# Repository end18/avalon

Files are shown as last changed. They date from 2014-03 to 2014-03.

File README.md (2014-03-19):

Avalon Gen3 Hasher
------------------

This project contains a circuit board, firmware and cgminer/bfgminer patch to get the new Avalon Gen3 ASICs (A3233Q48) hashing.

**Board features:**

  - Very efficient (~90%) DC/DC converter to power the ASICs
  - Adjustable voltage (0.75 - 1.25 V) to choose between efficiency and overclocking
  - USB-Interface to connect to a host running cgminer or bfgminer
  - TWI interface to chain multiple boards together
  - 100% flat surface on the bottom side to mount a usual heatsink
  - On-board temperature management
  - Fan connector with rotation speed measurement and PWM-control
  - Indicator LED to report USB-activity
  - 4-layer PCB for optimal heat/current transportation

**cgminer/bfgminer patch features:**

  - Reporting temperature, real ASIC frequency and fan-speed back to the host
  - Control of ASIC frequency in a big range from 62.5 to 5000 MHz in smallest possible steps
  - Control of a desired temperature

**Get support:**

* [Forum thread]
* - Will be updated soon.

**Get a board:**

Someone is selling some boards in the [Forum thread] soon.

  [Forum thread]: comming soon.

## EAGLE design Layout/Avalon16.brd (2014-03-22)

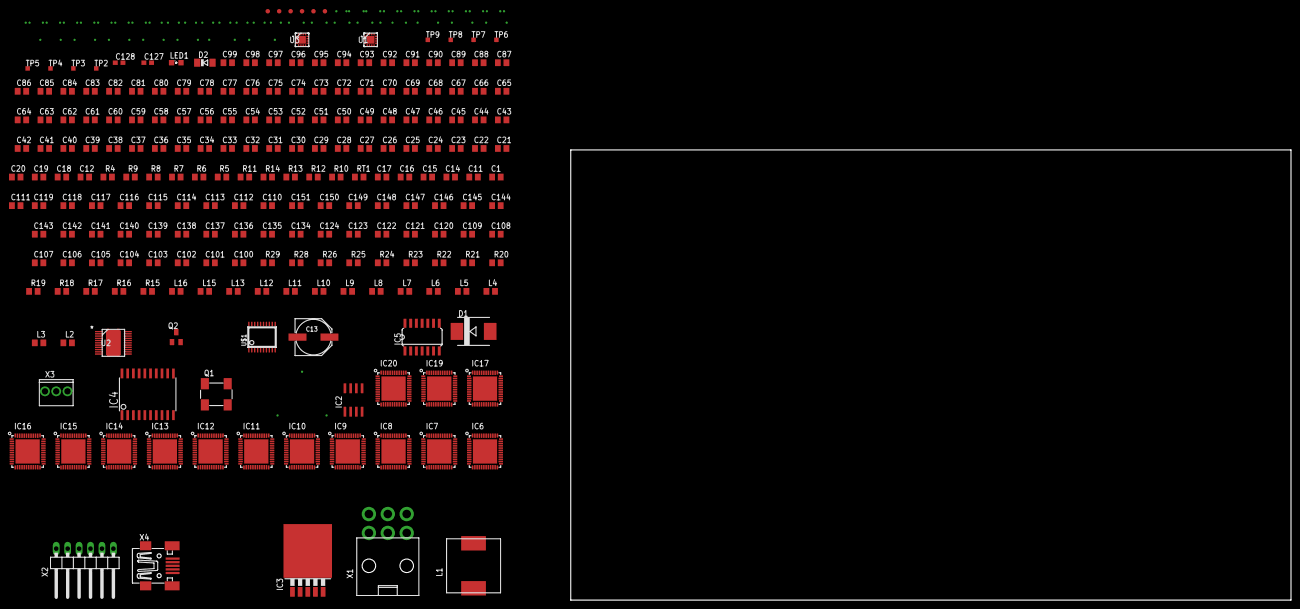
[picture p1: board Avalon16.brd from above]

Board: 2 copper layers, 160.0 x 100.0 mm, 264 parts (0 on the bottom side), 115 nets, no tracks yet.

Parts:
C1, C11, C14, C15, C16: 100n; C0805
C12, C18, C19, C20, C21, C22, C23, C24, C25, C26, C27, C28, C29, C30, C31, C32, C33, C34, C35, C36, C37, C38, C39, C40, C41, C42, C43, C44, C45, C46, C47, C48, C49, C50, C51, C52, C53, C54, C55, C56, C57, C58, C59, C60, C61, C62, C63, C64, C65, C66, C67, C68, C69, C70, C71, C72, C73, C74, C75, C76, C77, C78, C79, C80, C81, C82, C83, C84, C85, C86, C87, C88, C89, C90, C91, C92, C93, C94, C95, C96, C97, C98, C99, C100, C101, C102, C103, C104, C105, C106, C107, C108, C109, C110, C111, C112, C113, C114, C115, C116, C117, C118, C119, C120, C121, C122, C123, C124, C134, C135, C136, C137, C138, C139, C140, C141, C142, C143, C144, C145, C146, C147, C148, C149, C150, C151: 1µ; C0805
C13: 1000µ/6.3V/EEEFP0J102AP; PANASONIC_F
C17: 470p; C0805
C127, C128: 0.1µ; C0603
CAC_1: 1nF; 0603
CBST_1: 100nF; 0603
CINX_1, CINX_2: 100nF; 0603
CIN_1, CIN_6: 10uF; 0805
CIN_2, CIN_3, CIN_4, CIN_5: 22uF; 1812
COUT_1, COUT_6: 22uF; 0805
COUT_2, COUT_3, COUT_4, COUT_5: 100uF; 1812
CREG_1: 1uF; 1206
CR_1: 22nF; 0603
CSNUB_1: 2.2nF; 0603
CSS_1: 120pF; 0201
CSS_2: 220pF; 0201
CVDD_1: 4.7uF; 0805
D1: MBRS340T3G; SMC
D2: 4448; SOD80C
FID1, FID2, FID3, FID4, FID5, FID6: 1mm; FIDUCIAL
GND93: WB_GND
IC2: NB3L553DG; SO8
IC3: LM2576S-3.3; TO263-5
IC4: PIC16LF1459; SOIC20
IC5: 74HC02D; SO14
IC6, IC7, IC8, IC9, IC10, IC11, IC12, IC13, IC14, IC15, IC16, IC17, IC19, IC20: A3255Q48; QFN48
L1: 100µ / Würth 7447709101; WUERTH-7447709101
L2, L3, L4, L5, L6, L7, L8, L9, L10, L11, L12, L13, L15, L16: 100µ; L0805
L14, L18: 2.2uH; SRN8040
L17: 500nH; SER2009
LED1: green; SML0805
Q1: 7W-25-000MBB-T; 7W
Q2: IRFML8244TRPBF; SOT23
R4, R10, R11, R13: 10k; R0805
R5, R6: 390; R0805
R7, R8, R9, R12: 100; R0805
R14: 1k; R0805
R15, R16, R17, R18, R19, R20, R21, R22, R23, R24, R25, R26, R28, R29: 100k; R0805
RBST_1: 2.05; 0402
RENABLE_1: 1k; 0402
RENB_1: 100k; 0402
RENT_1: 200k; 0402
RFB1: 200k; 0402
RFB2: 24.9k; 0402
RFB3: 150k; 0402
RFB4: 187k; 0402
RFBB_1: 10k; 0402
RFBT_1: 2.49k; 0402
RPGOOD_1: 100k; 0402
RPG_1, RPG_2: 100k; 0402
RR_1: 66.5k; 0402
RSNUB_1: 3; 0402
RSS_1: 39k; 0603
RT1: 2k2; 0805
RTRIP_1: 180k; 0402
TP2, TP3, TP4, TP5, TP6, TP7, TP8, TP9: TPSQTP10SQ; TP10SQ
U1, U3: TPS62130RGTR; S-PVQFN-N16
U2: TPS53355DQPR; R-PSON-N22
U$1: GTL2003; TSSOP20
X1: Molex 45558-0003; MOLEX-45558-0003
X2: ISP; 1X06/270
X3: Molex 22-04-1031; MOLEX-22-04-1031
X4: Würth 65100516121 / TE 1734035-2; 32005-301

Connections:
1: CSS_1.2, U1.9
3: RFB1.2, RFB2.2, U1.5
4: L14.1, U1.1, U1.2, U1.3
6: RPG_1.2, U1.4
7: CAC_1.2, RFBB_1.1, RFBT_1.2, U2.1
10: CAC_1.1, CR_1.2, RR_1.1
11: CBST_1.2, RBST_1.1
13: CREG_1.1, RPGOOD_1.2, U2.18
14: CSNUB_1.1, RSNUB_1.2
15: RBST_1.2, U2.4
16: RENABLE_1.2, RENB_1.1, RENT_1.1
17: RENABLE_1.1, U2.2
18: RPGOOD_1.1, U2.3
19: RSS_1.1, U2.20
20: RTRIP_1.2, U2.21
24: CSS_2.2, U3.9
25: L18.1, U3.1, U3.2, U3.3
26: RFB3.2, RFB4.2, U3.5
27: RPG_2.2, U3.4
!MCLR: IC4.4, R7.1, X2.1
!RESET1: C26.2, IC6.44, R15.2
!RESET2: C27.2, IC7.44, R16.2
!RESET3: C36.2, IC8.44, R17.2
!RESET4: C45.2, IC9.44, R18.2
!RESET5: C54.2, IC10.44, R19.2
!RESET6: C63.2, IC11.44, R20.2
!RESET7: C72.2, IC12.44, R21.2
!RESET8: C81.2, IC13.44, R22.2
!RESET9: C90.2, IC14.44, R23.2
!RESET10: C99.2, IC15.44, R24.2
!RESET11: C12.2, IC16.44, R25.2
!RESET12: C116.2, IC17.44, R26.2
!RESET14: C134.2, IC19.44, R28.2
!RESET15: C143.2, IC20.44, R29.2
+0V9: COUT_1.1, IC8.7, IC9.7, IC10.7, IC12.7, IC13.7, IC14.7, IC15.7, IC16.7, IC17.7, IC19.7, IC20.7, L14.2, RFB2.1, RPG_1.1, U1.7, U1.14
+1V8: C127.2, COUT_6.1, IC6.24, IC6.37, IC7.24, IC7.37, IC8.24, IC8.37, IC9.24, IC9.37, IC10.24, IC10.37, IC11.24, IC11.37, IC12.24, IC12.37, IC13.24, IC13.37, IC14.24, IC14.37, IC15.24, IC15.37, IC16.24, IC16.37, IC17.24, IC17.37, IC19.24, IC19.37, IC20.24, IC20.37, L2.1, L3.1, L4.1, L5.1, L6.1, L7.1, L8.1, L9.1, L10.1, L11.1, L12.1, L13.1, L15.1, L16.1, L18.2, R15.1, R16.1, R17.1, R18.1, R19.1, R20.1, R21.1, R22.1, R23.1, R24.1, R25.1, R26.1, R28.1, R29.1, RFB4.1, RPG_2.1, U3.7, U3.14, U$1.2
+3V3: C1.2, C11.2, C13.+, C14.2, C15.2, C23.2, C24.2, C34.2, C35.2, C43.2, C44.2, C52.2, C53.2, C61.2, C62.2, C70.2, C71.2, C79.2, C80.2, C88.2, C89.2, C97.2, C98.2, C106.2, C107.2, C114.2, C115.2, C123.2, C124.2, C128.2, C141.2, C142.2, C150.2, C151.2, IC2.1, IC2.8, IC3.4, IC4.1, IC5.14, L1.2, Q1.4, R4.1, R5.1, R6.1, R10.1, R11.1, RT1.2, TP6.TP, U$1.19, U$1.20, X2.2
+12V: CINX_1.1, CINX_2.1, CIN_1.1, CIN_2.1, CIN_3.1, CIN_4.1, CIN_5.1, CIN_6.1, CVDD_1.1, D2.C, IC3.1, RENT_1.2, U1.10, U1.11, U1.12, U1.13, U2.12, U2.13, U2.14, U2.15, U2.16, U2.17, U2.19, U3.10, U3.11, U3.12, U3.13, X1.1, X1.2, X1.3, X3.2
CLK1: IC2.2, IC6.9, IC7.9, IC8.9, IC9.9, IC10.9, IC19.9, IC20.9
CLK2: IC2.3, IC11.9, IC12.9, IC13.9, IC14.9, IC15.9, IC16.9, IC17.9
CONFIG1_1V8_N: IC6.2, U$1.4
CONFIG1_1V8_P: IC6.1, U$1.3
CONFIG1_1_2_N: IC6.35, IC7.2
CONFIG1_1_2_P: IC6.36, IC7.1
CONFIG1_2_3_N: IC7.35, IC8.2
CONFIG1_2_3_P: IC7.36, IC8.1
CONFIG1_3_4_N: IC8.35, IC9.2
CONFIG1_3_4_P: IC8.36, IC9.1
CONFIG1_4_5_N: IC9.35, IC10.2
CONFIG1_4_5_P: IC9.36, IC10.1
CONFIG1_5_6_N: IC10.35, IC19.2
CONFIG1_5_6_P: IC10.36, IC19.1
CONFIG1_6_7_N: IC19.35, IC20.2
CONFIG1_6_7_P: IC19.36, IC20.1
CONFIG1_N: IC4.8, U$1.17
CONFIG1_P: IC4.9, U$1.18
CONFIG2_1V8_N: IC11.2, U$1.6
CONFIG2_1V8_P: IC11.1, U$1.5
CONFIG2_1_2_N: IC11.35, IC12.2
CONFIG2_1_2_P: IC11.36, IC12.1
CONFIG2_2_3_N: IC12.35, IC13.2
CONFIG2_2_3_P: IC12.36, IC13.1
CONFIG2_3_4_N: IC13.35, IC14.2
CONFIG2_3_4_P: IC13.36, IC14.1
CONFIG2_4_5_N: IC14.35, IC15.2
CONFIG2_4_5_P: IC14.36, IC15.1
CONFIG2_5_6_N: IC15.35, IC16.2
CONFIG2_5_6_P: IC15.36, IC16.1
CONFIG2_6_7_N: IC16.35, IC17.2
CONFIG2_6_7_P: IC16.36, IC17.1
CONFIG2_N: IC4.7, U$1.15
CONFIG2_P: IC4.6, U$1.16
DVDD: C18.2, C19.2, C20.2, C21.2, C22.2, C29.2, C30.2, C31.2, C32.2, C33.2, C38.2, C39.2, C40.2, C41.2, C42.2, C47.2, C48.2, C49.2, C50.2, C51.2, C56.2, C57.2, C58.2, C59.2, C60.2, C65.2, C66.2, C67.2, C68.2, C69.2, C74.2, C75.2, C76.2, C77.2, C78.2, C83.2, C84.2, C85.2, C86.2, C87.2, C92.2, C93.2, C94.2, C95.2, C96.2, C101.2, C102.2, C103.2, C104.2, C105.2, C109.2, C110.2, C111.2, C112.2, C113.2, C118.2, C119.2, C120.2, C121.2, C122.2, C136.2, C137.2, C138.2, C139.2, C140.2, C145.2, C146.2, C147.2, C148.2, C149.2, CBST_1.1, COUT_2.1, COUT_3.1, COUT_4.1, COUT_5.1, CR_1.1, CSNUB_1.2, IC6.3, IC6.4, IC6.10, IC6.11, IC6.13, IC6.14, IC6.15, IC6.18, IC6.19, IC6.20, IC6.21, IC6.22, IC6.25, IC6.26, IC6.28, IC6.29, IC6.30, IC6.31, IC6.32, IC6.33, IC6.34, IC6.39, IC6.40, IC6.41, IC6.42, IC6.45, IC6.46, IC6.47, IC6.48, IC7.3, IC7.4, IC7.10, IC7.11, IC7.13, IC7.14, IC7.15, IC7.18, IC7.19, IC7.20, IC7.21, IC7.22, IC7.25, IC7.26, IC7.28, IC7.29, IC7.30, IC7.31, IC7.32, IC7.33, IC7.34, IC7.39, IC7.40, IC7.41, IC7.42, IC7.45, IC7.46, IC7.47, IC7.48, IC8.3, IC8.4, IC8.10, IC8.11, IC8.13, IC8.14, IC8.15, IC8.18, IC8.19, IC8.20, IC8.21, IC8.22, IC8.25, IC8.26, IC8.28, IC8.29, IC8.30, IC8.31, IC8.32, IC8.33, IC8.34, IC8.39, IC8.40, IC8.41, IC8.42, IC8.45, IC8.46, IC8.47, IC8.48, IC9.3, IC9.4, IC9.10, IC9.11, IC9.13, IC9.14, IC9.15, IC9.18, IC9.19, IC9.20, IC9.21, IC9.22, IC9.25, IC9.26, IC9.28, IC9.29, IC9.30, IC9.31, IC9.32, IC9.33, IC9.34, IC9.39, IC9.40, IC9.41, IC9.42, IC9.45, IC9.46, IC9.47, IC9.48, IC10.3, IC10.4, IC10.10, IC10.11, IC10.13, IC10.14, IC10.15, IC10.18, IC10.19, IC10.20, IC10.21, IC10.22, IC10.25, IC10.26, IC10.28, IC10.29, IC10.30, IC10.31, IC10.32, IC10.33, IC10.34, IC10.39, IC10.40, IC10.41, IC10.42, IC10.45, IC10.46, IC10.47, IC10.48, IC11.3, IC11.4, IC11.10, IC11.11, IC11.13, IC11.14, IC11.15, IC11.18, IC11.19, IC11.20, IC11.21, IC11.22, IC11.25, IC11.26, IC11.28, IC11.29, IC11.30, IC11.31, IC11.32, IC11.33, IC11.34, IC11.39, IC11.40, IC11.41, IC11.42, IC11.45, IC11.46, IC11.47, IC11.48, IC12.3, IC12.4, IC12.10, IC12.11, IC12.13, IC12.14, IC12.15, IC12.18, IC12.19, IC12.20, IC12.21, IC12.22, IC12.25, IC12.26, IC12.28, IC12.29, IC12.30, IC12.31, IC12.32, IC12.33, IC12.34, IC12.39, IC12.40, IC12.41, IC12.42, IC12.45, IC12.46, IC12.47, IC12.48, IC13.3, IC13.4, IC13.10, IC13.11, IC13.13, IC13.14, IC13.15, IC13.18, IC13.19, IC13.20, IC13.21, IC13.22, IC13.25, IC13.26, IC13.28, IC13.29, IC13.30, IC13.31, IC13.32, IC13.33, IC13.34, IC13.39, IC13.40, IC13.41, IC13.42, IC13.45, IC13.46, IC13.47, IC13.48, IC14.3, IC14.4, IC14.10, IC14.11, IC14.13, IC14.14, IC14.15, IC14.18, IC14.19, IC14.20, IC14.21, IC14.22, IC14.25, IC14.26, IC14.28, IC14.29, IC14.30, IC14.31, IC14.32, IC14.33, IC14.34, IC14.39, IC14.40, IC14.41, IC14.42, IC14.45, IC14.46, IC14.47, IC14.48, IC15.3, IC15.4, IC15.10, IC15.11, IC15.13, IC15.14, IC15.15, IC15.18, IC15.19, IC15.20, IC15.21, IC15.22, IC15.25, IC15.26, IC15.28, IC15.29, IC15.30, IC15.31, IC15.32, IC15.33, IC15.34, IC15.39, IC15.40, IC15.41, IC15.42, IC15.45, IC15.46, IC15.47, IC15.48, IC16.3, IC16.4, IC16.10, IC16.11, IC16.13, IC16.14, IC16.15, IC16.18, IC16.19, IC16.20, IC16.21, IC16.22, IC16.25, IC16.26, IC16.28, IC16.29, IC16.30, IC16.31, IC16.32, IC16.33, IC16.34, IC16.39, IC16.40, IC16.41, IC16.42, IC16.45, IC16.46, IC16.47, IC16.48, IC17.3, IC17.4, IC17.10, IC17.11, IC17.13, IC17.14, IC17.15, IC17.18, IC17.19, IC17.20, IC17.21, IC17.22, IC17.25, IC17.26, IC17.28, IC17.29, IC17.30, IC17.31, IC17.32, IC17.33, IC17.34, IC17.39, IC17.40, IC17.41, IC17.42, IC17.45, IC17.46, IC17.47, IC17.48, IC19.3, IC19.4, IC19.10, IC19.11, IC19.13, IC19.14, IC19.15, IC19.18, IC19.19, IC19.20, IC19.21, IC19.22, IC19.25, IC19.26, IC19.28, IC19.29, IC19.30, IC19.31, IC19.32, IC19.33, IC19.34, IC19.39, IC19.40, IC19.41, IC19.42, IC19.45, IC19.46, IC19.47, IC19.48, IC20.3, IC20.4, IC20.10, IC20.11, IC20.13, IC20.14, IC20.15, IC20.18, IC20.19, IC20.20, IC20.21, IC20.22, IC20.25, IC20.26, IC20.28, IC20.29, IC20.30, IC20.31, IC20.32, IC20.33, IC20.34, IC20.39, IC20.40, IC20.41, IC20.42, IC20.45, IC20.46, IC20.47, IC20.48, L17.1, L17.2, RFBT_1.1, RR_1.2, U2.6, U2.7, U2.8, U2.9, U2.10, U2.11
FAN_PWM: IC4.5, R12.1
GND: C1.1, C11.1, C12.1, C13.-, C14.1, C15.1, C16.1, C17.1, C18.1, C19.1, C20.1, C21.1, C22.1, C23.1, C24.1, C25.2, C26.1, C27.1, C28.2, C29.1, C30.1, C31.1, C32.1, C33.1, C34.1, C35.1, C36.1, C37.2, C38.1, C39.1, C40.1, C41.1, C42.1, C43.1, C44.1, C45.1, C46.2, C47.1, C48.1, C49.1, C50.1, C51.1, C52.1, C53.1, C54.1, C55.2, C56.1, C57.1, C58.1, C59.1, C60.1, C61.1, C62.1, C63.1, C64.2, C65.1, C66.1, C67.1, C68.1, C69.1, C70.1, C71.1, C72.1, C73.2, C74.1, C75.1, C76.1, C77.1, C78.1, C79.1, C80.1, C81.1, C82.2, C83.1, C84.1, C85.1, C86.1, C87.1, C88.1, C89.1, C90.1, C91.2, C92.1, C93.1, C94.1, C95.1, C96.1, C97.1, C98.1, C99.1, C100.2, C101.1, C102.1, C103.1, C104.1, C105.1, C106.1, C107.1, C108.2, C109.1, C110.1, C111.1, C112.1, C113.1, C114.1, C115.1, C116.1, C117.2, C118.1, C119.1, C120.1, C121.1, C122.1, C123.1, C124.1, C127.1, C128.1, C134.1, C135.2, C136.1, C137.1, C138.1, C139.1, C140.1, C141.1, C142.1, C143.1, C144.2, C145.1, C146.1, C147.1, C148.1, C149.1, C150.1, C151.1, CINX_1.2, CINX_2.2, CIN_1.2, CIN_2.2, CIN_3.2, CIN_4.2, CIN_5.2, CIN_6.2, COUT_1.2, COUT_2.2, COUT_3.2, COUT_4.2, COUT_5.2, COUT_6.2, CREG_1.2, CSS_1.1, CSS_2.1, CVDD_1.2, D1.A, GND93.1, IC2.4, IC3.3, IC3.5, IC3.6, IC4.20, IC5.7, IC6.5, IC6.8, IC6.12, IC6.23, IC6.27, IC6.38, IC6.EXP, IC7.5, IC7.8, IC7.12, IC7.23, IC7.27, IC7.38, IC7.EXP, IC8.5, IC8.8, IC8.12, IC8.23, IC8.27, IC8.38, IC8.EXP, IC9.5, IC9.8, IC9.12, IC9.23, IC9.27, IC9.38, IC9.EXP, IC10.5, IC10.8, IC10.12, IC10.23, IC10.27, IC10.38, IC10.EXP, IC11.5, IC11.8, IC11.12, IC11.23, IC11.27, IC11.38, IC11.EXP, IC12.5, IC12.8, IC12.12, IC12.23, IC12.27, IC12.38, IC12.EXP, IC13.5, IC13.8, IC13.12, IC13.23, IC13.27, IC13.38, IC13.EXP, IC14.5, IC14.8, IC14.12, IC14.23, IC14.27, IC14.38, IC14.EXP, IC15.5, IC15.8, IC15.12, IC15.23, IC15.27, IC15.38, IC15.EXP, IC16.5, IC16.8, IC16.12, IC16.23, IC16.27, IC16.38, IC16.EXP, IC17.5, IC17.8, IC17.12, IC17.23, IC17.27, IC17.38, IC17.EXP, IC19.5, IC19.8, IC19.12, IC19.23, IC19.27, IC19.38, IC19.EXP, IC20.5, IC20.8, IC20.12, IC20.23, IC20.27, IC20.38, IC20.EXP, LED1.C, Q1.2, Q2.2, R13.2, R14.2, RENB_1.2, RFB1.1, RFB3.1, RFBB_1.2, RSNUB_1.1, RSS_1.2, RTRIP_1.1, TP9.TP, U1.6, U1.8, U1.15, U1.16, U1.17, U2.23, U3.6, U3.8, U3.15, U3.16, U3.17, U$1.1, X1.4, X1.5, X1.6, X2.3, X4.5, X4.M1, X4.M2, X4.M3, X4.M4
ICSPCLK: IC4.15, X2.5
ICSPDAT: IC4.16, X2.4
LED: IC4.2, R9.2
unnamed: IC20.36, TP2.TP
unnamed: C16.2, IC4.17
unnamed: D1.C, IC3.2, L1.1
unnamed: IC2.5, Q1.3
unnamed: D2.A, Q2.3, X3.1
unnamed: IC5.5, IC5.13, R8.1
unnamed: IC5.2, IC5.3, IC5.4
unnamed: Q2.1, R12.2, R13.1
unnamed: C17.2, IC5.6, R8.2
unnamed: R4.2, R7.2, X3.3
unnamed: LED1.A, R9.1
NTC: IC4.14, R14.1, RT1.1
OSC_EN: IC4.3, Q1.1
REPORT_1V8_N: IC6.16, IC7.16, IC8.16, IC9.16, IC10.16, IC11.16, IC12.16, IC13.16, IC14.16, IC15.16, IC16.16, IC17.16, IC19.16, IC20.16, U$1.8
REPORT_1V8_P: IC6.17, IC7.17, IC8.17, IC9.17, IC10.17, IC11.17, IC12.17, IC13.17, IC14.17, IC15.17, IC16.17, IC17.17, IC19.17, IC20.17, U$1.7
REPORT_CLK: IC4.10, IC5.1
REPORT_DATA: IC4.12, IC5.10
REPORT_N: IC5.8, IC5.9, IC5.12, R6.2, U$1.13
REPORT_P: IC5.11, R5.2, U$1.14
SCL: IC4.11, R11.2, TP7.TP
SDA: IC4.13, R10.2, TP8.TP
USB_DM: IC4.18, X4.2
USB_DP: IC4.19, X4.3
VDD_PLL1: C25.1, IC6.6, L2.2
VDD_PLL2: C28.1, IC7.6, L3.2
VDD_PLL3: C37.1, IC8.6, L4.2
VDD_PLL4: C46.1, IC9.6, L5.2
VDD_PLL5: C55.1, IC10.6, L6.2
VDD_PLL6: C64.1, IC11.6, L7.2
VDD_PLL7: C73.1, IC12.6, L8.2
VDD_PLL8: C82.1, IC13.6, L9.2
VDD_PLL9: C91.1, IC14.6, L10.2
VDD_PLL10: C100.1, IC15.6, L11.2
VDD_PLL11: C108.1, IC16.6, L12.2
VDD_PLL12: C117.1, IC17.6, L13.2
VDD_PLL14: C135.1, IC19.6, L15.2
VDD_PLL15: C144.1, IC20.6, L16.2

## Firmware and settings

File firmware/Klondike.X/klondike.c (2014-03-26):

/********
 * Klondike ASIC Miner - klondike.c - cmd processing and host protocol support 
 * 
 * (C) Copyright 2014 Bang, YongHee.
 * (C) Copyright 2013 Chris Savery. 
 *
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
 */
#include "GenericTypeDefs.h"
#include "Compiler.h"
#include <xc.h>
#include "klondike.h"

const IDENTITY ID = { 0x10, "IMA", 0xDEADBEEF };
//const char FwPwd[] = FWPWD;

//DWORD BankRanges[8] = { 0, 0x40000000, 0x2aaaaaaa, 0x20000000, 0x19999999, 0x15555555, 0x12492492, 0x10000000 };
DWORD BankRanges[7] = { 0, 613566756, 1227133512, 1840700268, 2454267024, 3067833780, 3681400536 };
BYTE WorkNow, BankSize, ResultQC, SlowTick, VerySlowTick, TimeOut, TempTarget, LastTemp, FanLevel;
BYTE SlaveAddress = MASTER_ADDRESS;
BYTE HashTime;
volatile WORKSTATUS Status = {'I',0,0,0,0,0,0,0,0, WORK_TICKS, 0 };
WORKCFG Cfg = { DEFAULT_HASHCLOCK, DEFAULT_TEMP_TARGET, 0, 0, 0 };
WORKTASK WorkQue[MAX_WORK_COUNT];
volatile BYTE ResultQue[6];
DWORD CLOCK_LOW_CHG;
DWORD ClockCfg[2];

INT16 Step, Error, LastError;

DWORD NonceRanges[7];

extern I2CSTATE I2CState;
extern DWORD PrecalcHashes[6];

void ProcessCmd(char *cmd)
{
    // cmd is one char, dest address 1 byte, data follows
    // we already know address is ours here
    switch(cmd[0]) {
        case 'W': // queue new work
            if( Status.WorkQC < MAX_WORK_COUNT-1 ) {
                WorkQue[ (WorkNow + Status.WorkQC++) & WORKMASK ] = *(WORKTASK *)(cmd+2);
                if(Status.State == 'R') {
                    AsicPushWork();
                }
            }
            SendCmdReply(cmd, (char *)&Status, sizeof(Status));
            Status.Noise = Status.ErrorCount = 0;
            break;
        case 'A': // abort work, reply status has hash completed count
            Status.WorkQC = WorkNow = 0;
            Status.State = 'R';
            SendCmdReply(cmd, (char *)&Status, sizeof(Status));
            Status.Noise = Status.ErrorCount = 0;
            break;
        case 'I': // return identity 
            SendCmdReply(cmd, (char *)&ID, sizeof(ID));
            break;
        case 'S': // return status 
            SendCmdReply(cmd, (char *)&Status, sizeof(Status));
            Status.Noise = Status.ErrorCount = 0;
            break;
        case 'C': // set config values 
            if( *(WORD *)&cmd[2] != 0 ) {
                Cfg = *(WORKCFG *)(cmd+2);
                if(Cfg.HashClock < MIN_HASH_CLOCK)
                    Cfg.HashClock = MIN_HASH_CLOCK;
                if(Cfg.HashClock > MAX_HASH_CLOCK)
                    Cfg.HashClock = MAX_HASH_CLOCK;
                UpdateClock(Cfg.HashClock);
                if(Cfg.TempTarget != 0)
                    TempTarget = Cfg.TempTarget;
                else
                    Cfg.TempTarget = DEFAULT_TEMP_TARGET;
            }
            SendCmdReply(cmd, (char *)&Cfg, sizeof(Cfg));
            break;
        case 'E': // enable/disable work
            HASH_CLK_EN = (cmd[2] == '1');
            Status.State = (cmd[2] == '1') ? 'R' : 'D';
            SendCmdReply(cmd, (char *)&Status, sizeof(Status));
            Status.Noise = Status.ErrorCount = 0;
            break;
        //case 'F': // enter firmware update mode
        //    for(BYTE n = 0; n < sizeof(FwPwd); n++)
	//	if(FwPwd[n] != cmd[2+n])
        //            return;
        //    UpdateFirmware();
        //    break;
        default:
            break;
        }
    LED_On();
}

void AsicPushWork(void)
{
    AsicPreCalc(&WorkQue[WorkNow]);
    Status.WorkID = WorkQue[WorkNow].WorkID;
    SendAsicData(&WorkQue[WorkNow]);
    WorkNow = (WorkNow+1) & WORKMASK;
    Status.HashCount = 0;
    TMR0 = HashTime;
    Status.State = 'W';
    Status.WorkQC--;
}

void DetectAsics(void)
{
    Status.ChipCount = 14;

    // pre-calc nonce range values
    BankSize = (Status.ChipCount)/2;
    Status.MaxCount = WORK_TICKS / BankSize / 2;

    NonceRanges[0] = 0;
    for(BYTE x = 1; x < BankSize; x++)
        NonceRanges[x] = NonceRanges[x-1] + BankRanges[BankSize-1];

    Status.State = 'R';
    Status.HashCount = 0;
}

// ISR functions
void WorkTick(void)
{
    TMR0 += HashTime;
    TMR0IF = 0;

    if((Status.State == 'W') && (++Status.HashCount == Status.MaxCount)) {
        if(Status.WorkQC > 0) {
            Status.State = 'P';
        }
        else {
            Status.State = 'R';
        }
    }

    if(++SlowTick == 0) {
        LED_Off();
        Status.Temp = ADRESH;
        ADCON0bits.GO_nDONE = 1;
        if((++VerySlowTick % 15) == 0) {
            UpdateFanLevel();
        }
        //CheckFanSpeed();
    }
   //if((SlowTick & 3) == 0)
   //I2CPoll();
}

void ResultRx(void)
{
    TimeOut = 0;

    while(ResultQC < 4) {
        if(RCIF) {
            ResultQue[2+ResultQC++] = RCREG;
            TimeOut = 0;
        }
        if(TimeOut++ > 32) {
            Status.Noise++;
            goto outrx;
        }
        if(RCSTAbits.OERR) { // error occured, either overun or no more bits
            if(Status.State == 'W') {
                Status.ErrorCount++;
            }
            goto outrx;
        }
    }
    
    if(Status.State == 'W') {
        ResultQue[0] = '=';
        ResultQue[1] = Status.WorkID;
        SendCmdReply(&ResultQue, &ResultQue+1, sizeof(ResultQue)-1);
    }

outrx:
    RESET_RX();
    ResultQC = 0;
    IOCBF = 0;
}

// Housekeeping functons
// function that adjusts fan speed according to target and current temperatures
void UpdateFanLevel(void)
{
    Error = Status.Temp - TempTarget;
    Step = 1*Error - 0.5*LastError - 8*(LastTemp - Status.Temp);

    if(FanLevel + Step > 75 && FanLevel + Step <= 255) {
        FanLevel += Step;
    }
    else if(FanLevel + Step > 255) {
        FanLevel = 255;
    }
    else if(FanLevel + Step < 75) {
        FanLevel = 75;
    }

    LastTemp = Status.Temp;
    LastError = Error;
    // this is just temporary - fan speed should be measured RPM of a fan (will change it when it will be functional)
    PWM1DCH = Status.FanSpeed = FanLevel;
}

// Init functions
void InitFAN(void)
{
    FAN_TRIS = 1;
    PWM1CON = 0;
    PR2 = 0xFF;
    PWM1CON = 0xC0;
    PWM1DCH = FanLevel = DEFAULT_FAN_TARGET;
    PWM1DCL = 0;
    TMR2IF = 0;
    T2CONbits.T2CKPS = 1;
    TMR2ON = 1;
    FAN_TRIS = 0;
    PWM1OE=1;

    // for Fan Tach reading
    //T1GSEL = 1;
    //IOCAN3 = 1;
    //IOCAF3 = 0;
}

void InitTempSensor(void)
{ 
    THERM_TRIS=1;
    //TEMP_INIT;
    //FVREN = 1;
    ADCON0bits.CHS = TEMP_THERMISTOR;
    ADCON0bits.ADON = 1;
    ADCON1bits.ADFM = 0;
    ADCON1bits.ADCS = 6;
    ADCON1bits.ADPREF = 0;
    ADCON2bits.TRIGSEL = 0;
    TempTarget = DEFAULT_TEMP_TARGET;
}

void InitWorkTick(void)
{
    UpdateClock(DEFAULT_HASHCLOCK);
    TMR0CS = 0;
    OPTION_REGbits.PSA = 0;
    OPTION_REGbits.PS = 7;
    TMR0 = HashTime;

    HASH_TRIS_0P = 0;
    HASH_TRIS_0N = 0;
    HASH_TRIS_1P = 0;
    HASH_TRIS_1N = 0;
    HASH_IDLE();
    HASH_CLK_TRIS = 0;
    HASH_CLK_EN = 0;
}
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

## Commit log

2014-03-20 add level translator
    [Avalon16.sch]
2014-03-22 change power units
    [Avalon16.brd]

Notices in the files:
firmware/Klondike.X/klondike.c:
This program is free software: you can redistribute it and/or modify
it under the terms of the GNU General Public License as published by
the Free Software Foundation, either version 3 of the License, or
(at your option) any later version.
